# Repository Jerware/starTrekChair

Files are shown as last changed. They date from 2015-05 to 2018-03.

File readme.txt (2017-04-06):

This code adds sound & light to Adam Savage's Star Trek captain's chair
featured in the following Tested video:

https://youtu.be/jaVi06DaTk0

It compiles on Teensy 3.1, requires a Teensy Audio Board, and the two
code bases are designed to work in parallel. Both are available in this
GITHUB repository:

https://github.com/Jerware/

Jeremy Williams wrote the code and designed the sound/LED hardware.

Update April 2017:
This is the second revision of the code & hardware. The sound board now acts
as a master and the LED board is a slave. All buttons are routed solely
to the sound board, and it sends signals to the LED board via hardware
serial. There is also a pin expander IC incorporated instead of the pins
on the underside of the Teensy 3.1.

A PCB is now available from OSH Park:
https://oshpark.com/shared_projects/ZAHpgs72

As always, thanks to the amazing library developers for keeping Arduino coding
from becoming a chore. You are all giants. I'll monitor the feedback on Github
from time to time but this code should be considered unsupported. #LLAP.

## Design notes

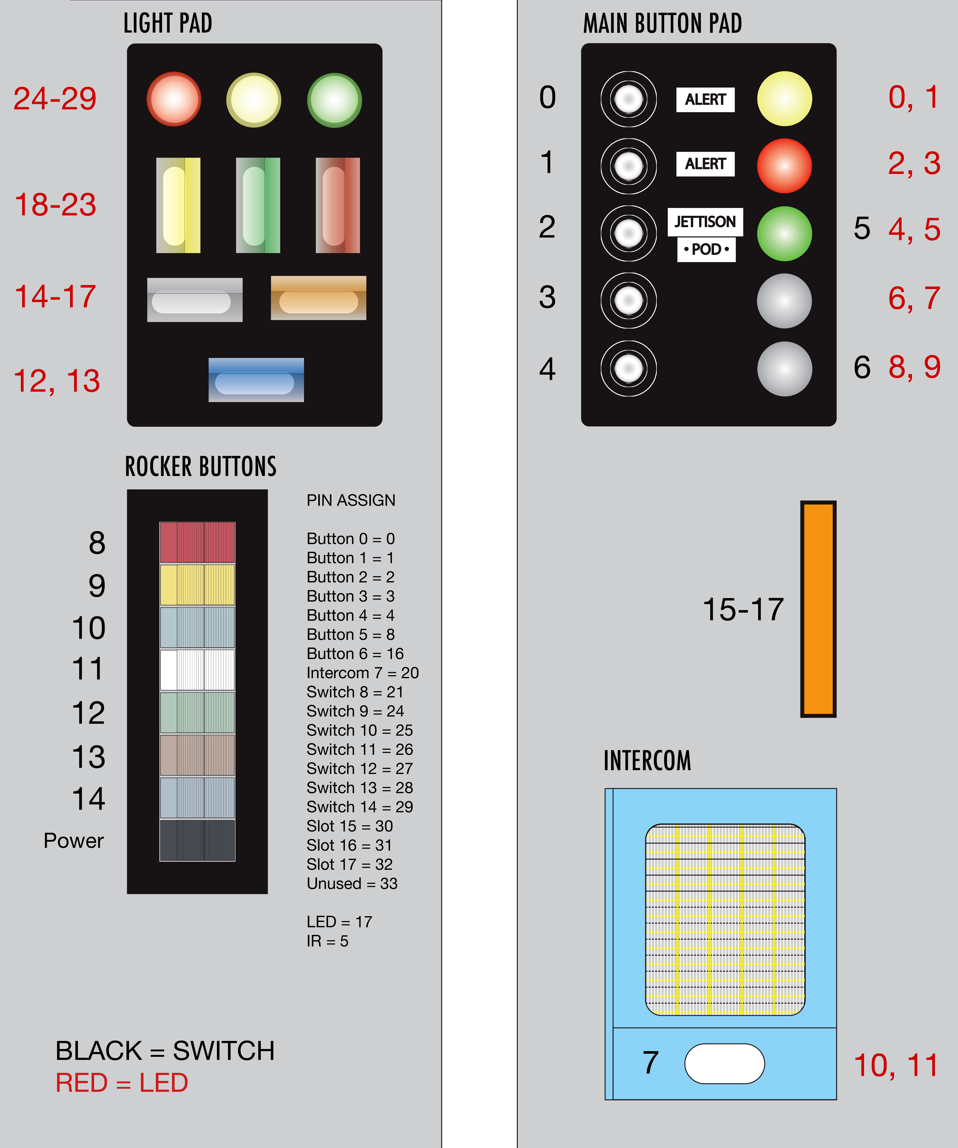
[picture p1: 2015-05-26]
tosChair.png

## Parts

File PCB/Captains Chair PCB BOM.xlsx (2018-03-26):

PART | QUANTITY | TYPE | VALUE | LINK
R1 | 1 | Resistor | 220 Ohm | https://www.digikey.com/product-detail/en/stackpole-electronics-inc/CF14JT220R/CF14JT220RCT-ND/1830334
R2 | 1 | Resistor | 10 kOhm | https://www.digikey.com/product-detail/en/stackpole-electronics-inc/CF14JT10K0/CF14JT10K0CT-ND/1830374
R3 | 1 | Resistor | 2.2 kOhm | https://www.digikey.com/product-detail/en/stackpole-electronics-inc/CF14JT2K20/CF14JT2K20CT-ND/1830358
R4 | 1 | Resistor | 47 Ohm | https://www.digikey.com/product-detail/en/stackpole-electronics-inc/CFM14JT47R0/S47QCT-ND/2617762
R5 | 1 | Resistor | 220 Ohm | https://www.digikey.com/product-detail/en/stackpole-electronics-inc/CF14JT220R/CF14JT220RCT-ND/1830334
D1 | 1 | Diode | 1N4004 | https://www.digikey.com/product-detail/en/micro-commercial-co/1N4004-TP/1N4004-TPMSCT-ND/773691
T1 | 1 | Transistor | 2N3904 | https://www.digikey.com/product-detail/en/on-semiconductor/2N3904BU/2N3904FS-ND/1413
C1 | 1 | Capacitor | 10uf | https://www.digikey.com/product-detail/en/panasonic-electronic-components/ECA-1HM100/P5178-ND/245037
C2 | 1 | Capacitor | .1uf | https://www.digikey.com/product-detail/en/vishay-bc-components/K104K10X7RF5UH5/BC2665CT-ND/2356879
LIGHTS | 1 | Microcontroller | Teensy 3.2 | https://www.pjrc.com/store/teensy32_pins.html
SOUND | 1 | Microcontroller | Teensy 3.2 | https://www.pjrc.com/store/teensy32_pins.html
microSD/AUDIO JACK | 1 | Sound Board | Audio Adaptor Board | https://www.pjrc.com/store/teensy3_audio.html
PWR LED | 1 | LED | 5mm | https://www.adafruit.com/product/679
MCP23017SP | 1 | Port Expander | 16 input/output | https://www.adafruit.com/product/732
SN74HCT245DIL20 | 1 | Level shifter | 20DIP | https://www.digikey.com/product-detail/en/texas-instruments/SN74HCT245N/296-1612-5-ND/277258
7805TV | 1 | Regulator | 3.3V | https://www.digikey.com/product-detail/en/texas-instruments/UCC283T-3/296-11413-5-ND/381558
SWITCHES | 1 | 10x2 | Switch connector | https://www.digikey.com/product-detail/en/sullins-connector-solutions/SBH11-PBPC-D10-ST-BK/S9172-ND/1990065
MISC
Switches Cable | 1 | 10x2 | Female Cable Connector | https://www.amazon.com/Pc-Accessories-Connectors-Yellow-20cm-2PK/dp/B01G7GXHAA/
LEDS, POWER, IR | 3 | Terminal Blocks |  | https://www.digikey.com/product-detail/en/te-connectivity-amp-connectors/282837-2/A113320-ND/2187973
Female Headers for Teensys & Sound | 6 | 14x1 |  | https://www.pjrc.com/store/socket_14x1.html
Male headers for sound board | 2 | 14x1 |  | https://www.pjrc.com/store/header_14x1.html

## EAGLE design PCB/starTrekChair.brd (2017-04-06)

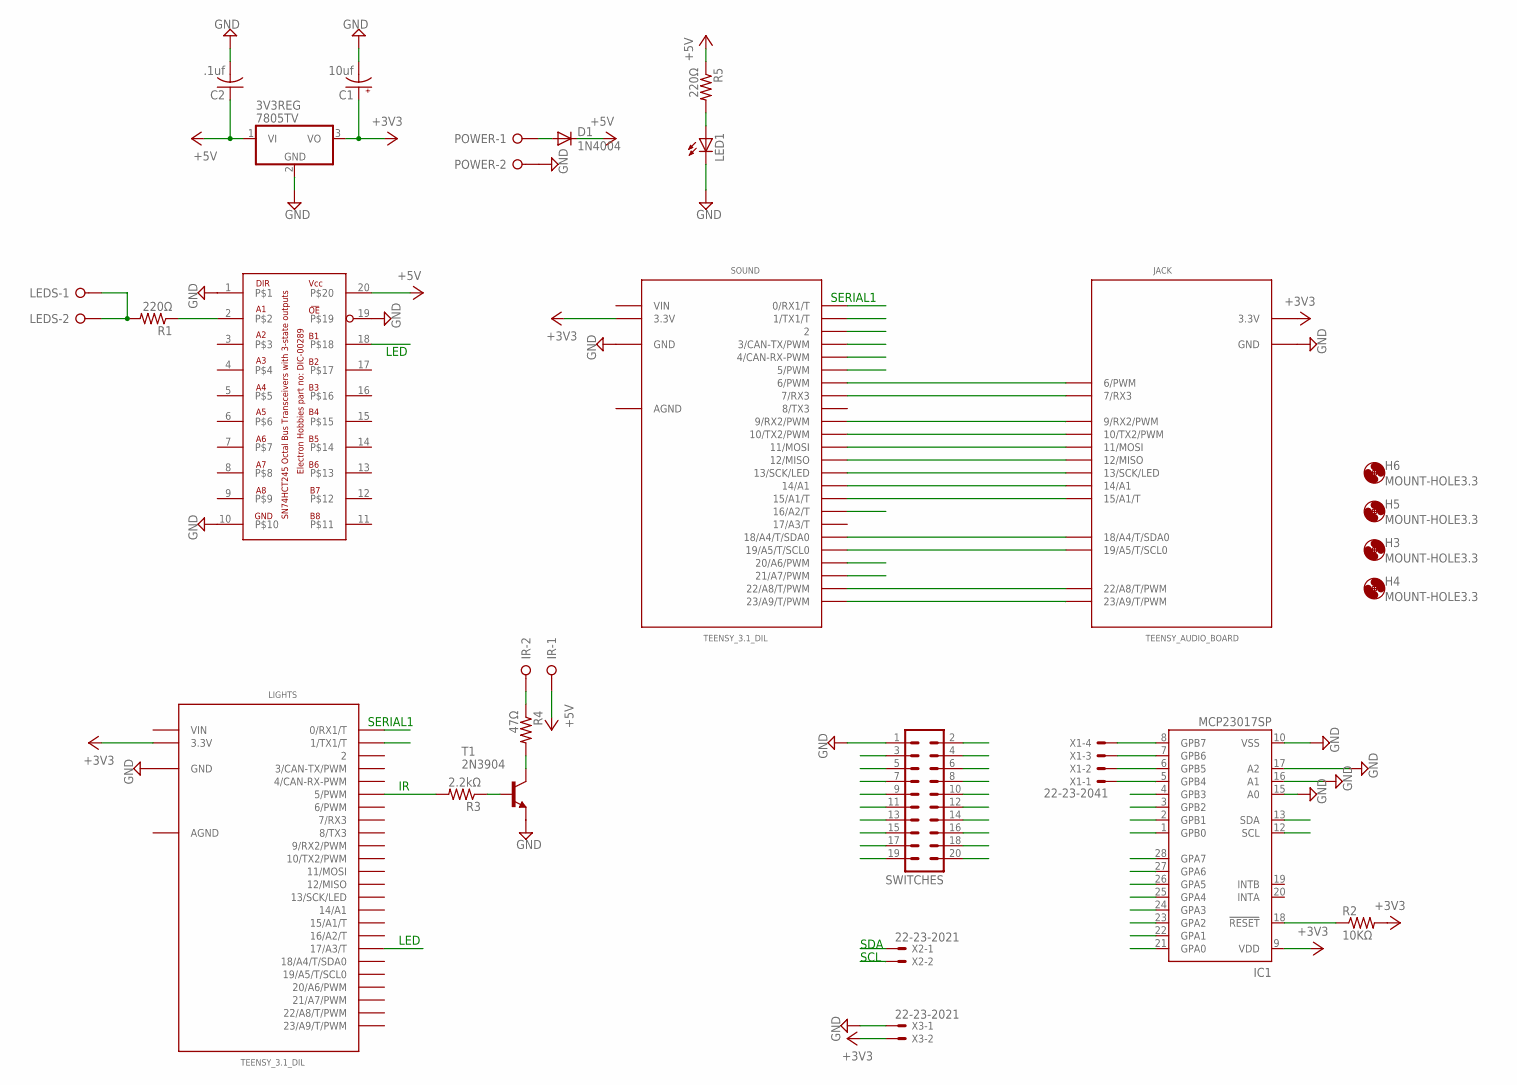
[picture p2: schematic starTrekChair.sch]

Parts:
3V3REG: 7805TV; TO220V
C1: 10uf; E2-4
C2: .1uf; C050-025X075
D1: 1N4004; DO41-10
H3, H4, H5, H6: MOUNT-HOLE3.3; 3,3
IC1: MCP23017SP; DIL28-3
IR: W237-02P; W237-132
JACK: TEENSY_AUDIO_BOARD
LED1: LED5MM
LEDS: W237-02P; W237-132
LIGHTS: TEENSY_3.1_DIL; TEENSY3-DIL
POWER: W237-02P; W237-132
R1, R5: 220Ω; 0207/10
R2: 10KΩ; 0207/10
R3: 2.2kΩ; 0207/10
R4: 47Ω; 0207/10
SOUND: TEENSY_3.1_DIL; TEENSY3-DIL
SWITCHES: ML20
T1: 2N3904; TO92
U$1: SN74HCT245DIL20; DIL20
X1: 22-23-2041
X2, X3: 22-23-2021

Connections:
+3V3: 3V3REG.3 (VO), C1.+, IC1.9 (VDD), JACK.3.3V, LIGHTS.3.3V, R2.2, SOUND.3.3V, X3.2
+5V: 3V3REG.1 (VI), C2.1, D1.C, IR.1, R5.1, U$1.20
AGND: LIGHTS.AGND, SOUND.AGND
GND: 3V3REG.2 (GND), C1.-, C2.2, IC1.10 (VSS), IC1.15 (A0), IC1.16 (A1), IC1.17 (A2), JACK.GND, LED1.K (C), LIGHTS.GND, POWER.2, SOUND.GND, SWITCHES.1, T1.3 (E), U$1.1, U$1.10, U$1.19, X3.1
LED: LIGHTS.17/A3 (17/A3/T), U$1.18
unnamed: JACK.6 (6/PWM), SOUND.6 (6/PWM)
unnamed: JACK.7 (7/RX3), SOUND.7 (7/RX3)
unnamed: JACK.12 (12/MISO), SOUND.12 (12/MISO)
unnamed: JACK.11 (11/MOSI), SOUND.11 (11/MOSI)
unnamed: JACK.10 (10/TX2/PWM), SOUND.10 (10/TX2/PWM)
unnamed: JACK.9 (9/RX2/PWM), SOUND.9 (9/RX2/PWM)
unnamed: JACK.23/A9 (23/A9/T/PWM), SOUND.23/A9 (23/A9/T/PWM)
unnamed: JACK.22/A8 (22/A8/T/PWM), SOUND.22/A8 (22/A8/T/PWM)
unnamed: IC1.18 (!RESET), R2.1
unnamed: LIGHTS.5 (5/PWM), R3.2
unnamed: JACK.15/A1 (15/A1/T), SOUND.15/A1 (15/A1/T)
unnamed: JACK.14/A0 (14/A1), SOUND.14/A0 (14/A1)
unnamed: JACK.13 (13/SCK/LED), SOUND.13 (13/SCK/LED)
unnamed: R1.1, U$1.2
unnamed: LEDS.1, LEDS.2, R1.2
unnamed: IR.2, R4.1
unnamed: R4.2, T1.1 (C)
unnamed: IC1.5 (GPB4), X1.1
unnamed: IC1.6 (GPB5), X1.2
unnamed: IC1.7 (GPB6), X1.3
unnamed: IC1.8 (GPB7), X1.4
unnamed: R3.1, T1.2 (B)
unnamed: LED1.A, R5.2
unnamed: D1.A, POWER.1
RIBBON2: SOUND.2, SWITCHES.2
RIBBON3: SOUND.3 (3/CAN-TX/PWM), SWITCHES.3
RIBBON4: SOUND.4 (4/CAN-RX-PWM), SWITCHES.4
RIBBON5: SOUND.5 (5/PWM), SWITCHES.5
RIBBON6: SOUND.16/A2 (16/A2/T), SWITCHES.6
RIBBON7: SOUND.20/A6 (20/A6/PWM), SWITCHES.7
RIBBON8: SOUND.21/A7 (21/A7/PWM), SWITCHES.8
RIBBON9: IC1.21 (GPA0), SWITCHES.9
RIBBON10: IC1.22 (GPA1), SWITCHES.10
RIBBON11: IC1.23 (GPA2), SWITCHES.11
RIBBON12: IC1.24 (GPA3), SWITCHES.12
RIBBON13: IC1.25 (GPA4), SWITCHES.13
RIBBON14: IC1.26 (GPA5), SWITCHES.14
RIBBON15: IC1.27 (GPA6), SWITCHES.15
RIBBON16: IC1.28 (GPA7), SWITCHES.16
RIBBON17: IC1.1 (GPB0), SWITCHES.17
RIBBON18: IC1.2 (GPB1), SWITCHES.18
RIBBON19: IC1.3 (GPB2), SWITCHES.19
RIBBON20: IC1.4 (GPB3), SWITCHES.20
SCL: IC1.12 (SCL), JACK.19/A5 (19/A5/T/SCL0), SOUND.19/A5 (19/A5/T/SCL0), X2.2
SDA: IC1.13 (SDA), JACK.18/A4 (18/A4/T/SDA0), SOUND.18/A4 (18/A4/T/SDA0), X2.1
S_RX: LIGHTS.1 (1/TX1/T), SOUND.0 (0/RX1/T)
S_TX: LIGHTS.0 (0/RX1/T), SOUND.1 (1/TX1/T)
VIN: LIGHTS.VIN, SOUND.VIN

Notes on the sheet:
LED
SERIAL1
SDA
SCL

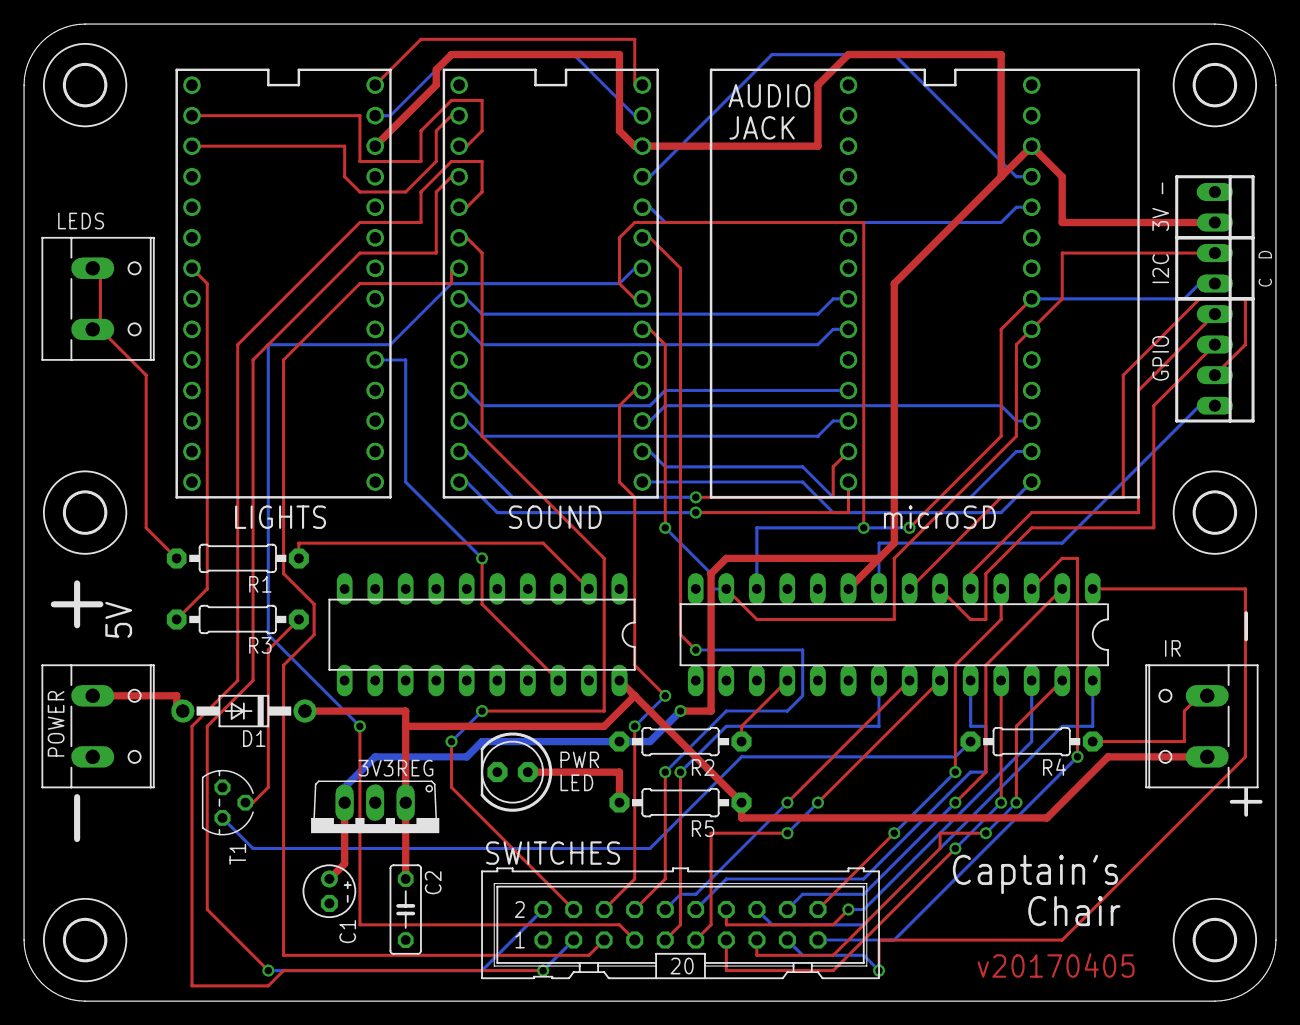
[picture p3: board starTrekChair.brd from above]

Board: 2 copper layers, 104.1 x 81.3 mm, 29 parts (0 on the bottom side), 53 nets.

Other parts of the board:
H1, H2: MOUNT-HOLE3.3; 3,3

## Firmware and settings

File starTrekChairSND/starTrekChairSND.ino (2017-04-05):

// starTrekChairSND release 20160319
//
// This code controls the LEDs on Adam Savage's Star Trek captain's chair
// featured in the following Tested video:
//
// https://youtu.be/jaVi06DaTk0
//
// It compiles on Teensy 3.1 and is designed to work in parallel with the 
// sound code. Both sources are available in this GITHUB repository:
//
// https://github.com/Jerware/
//
// Jeremy Williams wrote the code and designed the sound/LED hardware.
// This is the second revision of the code & hardware. The sound board now
// acts as a master and the LED board is a slave. All buttons are routed
// solely to the sound board, and it sends signals to the LED board
// via hardware serial. There is also a pin expander IC incorporated 
// instead of the pins on the underside of the Teensy 3.1.
//
// As always, thanks to the amazing library developers for keeping Arduino coding
// from becoming a chore. You are all giants. I'll monitor the feedback on Github
// from time to time but this code should be considered unsupported. #LLAP.

#include <Audio.h>
#include <Wire.h>
#include <SPI.h>
#include <SD.h>
#include <Bounce2.h>
#include <Bounce2mcp.h>
#include <Entropy.h>
#include <FastLED.h>
#include "Adafruit_MCP23017.h"

#define HWSERIAL Serial1

Adafruit_MCP23017 mcp;

byte lastButton;
boolean switchClosed;
int slotMode;
boolean moviePlaying;

// GUItool: begin automatically generated code
AudioPlaySdWav           soundButtons;       //xy=223,156
AudioPlaySdWav           soundRocker;       //xy=225,228
AudioPlaySdWav           soundBackground;       //xy=225,395
AudioPlaySdWav           soundIntercom;       //xy=230,489
AudioMixer4              mixer3;         //xy=528,500
AudioMixer4              mixer1;         //xy=529,307
AudioMixer4              mixer2;         //xy=724,398
AudioFilterBiquad        intercomFilter;        //xy=714,554
AudioOutputI2S           i2s1;           //xy=892,494
AudioConnection          patchCord1(soundButtons, 0, mixer1, 0);
AudioConnection          patchCord2(soundButtons, 1, mixer1, 1);
AudioConnection          patchCord3(soundRocker, 0, mixer1, 2);
AudioConnection          patchCord4(soundRocker, 1, mixer1, 3);
AudioConnection          patchCord5(soundBackground, 0, mixer2, 1);
AudioConnection          patchCord6(soundBackground, 1, mixer2, 2);
AudioConnection          patchCord7(soundIntercom, 0, mixer3, 0);
AudioConnection          patchCord8(soundIntercom, 1, mixer3, 1);
AudioConnection          patchCord9(mixer3, intercomFilter);
AudioConnection          patchCord10(mixer1, 0, mixer2, 0);
AudioConnection          patchCord11(intercomFilter, 0, i2s1, 1);
AudioConnection          patchCord12(mixer2, 0, i2s1, 0);
// GUItool: end automatically generated code

// Create an object to control the audio shield.
AudioControlSGTL5000 audioShield;

// Bounce Teensy Pins
Bounce button1 = Bounce();
Bounce button2 = Bounce();
Bounce button3 = Bounce();
Bounce button4 = Bounce();
Bounce button5 = Bounce();
Bounce button6 = Bounce();
Bounce button7 = Bounce();

// Debounce MCP23017 Pins
BounceMcp buttonIntercom = BounceMcp();
BounceMcp rocker1 = BounceMcp();
BounceMcp rocker2 = BounceMcp();
BounceMcp rocker3 = BounceMcp();
BounceMcp rocker4 = BounceMcp();
BounceMcp rocker5 = BounceMcp();
BounceMcp rocker6 = BounceMcp();
BounceMcp rocker7 = BounceMcp();
BounceMcp slot1 = BounceMcp();
BounceMcp slot2 = BounceMcp();
BounceMcp slot3 = BounceMcp();
BounceMcp other1 = BounceMcp();


void setup() {
  Serial.begin(57600);
  HWSERIAL.begin(38400);
  delay(1000);
  Serial.println("Hello there!");

  // Start I²C bus as master
  Wire.begin();

  mcp.begin();      // use default address 0

  Entropy.Initialize();

  // Configure the pushbutton pins for pullups.
  // Each button should connect from the pin to GND.
  // Teensy Pins
  pinMode(2, INPUT_PULLUP);
  pinMode(3, INPUT_PULLUP);
  pinMode(4, INPUT_PULLUP);
  pinMode(5, INPUT_PULLUP);
  pinMode(16, INPUT_PULLUP);
  pinMode(20, INPUT_PULLUP);
  pinMode(21, INPUT_PULLUP);
  button1.attach(2);
  button2.attach(3);
  button3.attach(4);
  button4.attach(5);
  button5.attach(16);
  button6.attach(20);
  button7.attach(21);
  button1.interval(35);
  button2.interval(35);
  button3.interval(35);
  button4.interval(35);
  button5.interval(35);
  button6.interval(35);
  button7.interval(35);

  // MCP23017 Pins
  for (int p=0; p<16; p++)
  {
    mcp.pinMode(p, INPUT);
    mcp.pullUp(p, HIGH);  // turn on a 100K pullup internally
  }
  buttonIntercom.attach(mcp, 0, 35);
  rocker1.attach(mcp, 1, 35);
  rocker2.attach(mcp, 2, 35);
  rocker3.attach(mcp, 3, 35);
  rocker4.attach(mcp, 4, 35);
  rocker5.attach(mcp, 5, 35);
  rocker6.attach(mcp, 6, 35);
  rocker7.attach(mcp, 7, 35);
  slot1.attach(mcp, 8, 35);
  slot2.attach(mcp, 9, 35);
  slot3.attach(mcp, 10, 35);

  // Audio connections require memory to work.  For more
  // detailed information, see the MemoryAndCpuUsage example
  AudioMemory(64);

  // turn on the output
  audioShield.enable();
  audioShield.volume(.8);
  delay(1000);
  intercomFilter.setHighpass(0, 800, 0.707);

  // by default the Teensy 3.1 DAC uses 3.3Vp-p output
  // if your 3.3V power has noise, switching to the
  // internal 1.2V reference can give you a clean signal
  //dac.analogReference(INTERNAL);

  // reduce the gain on mixer channels, so more than 1
  // sound can play simultaneously without clipping
  float gainLevel = .4;
  mixer2.gain(0, gainLevel);
  mixer2.gain(1, gainLevel);
  mixer2.gain(2, gainLevel);
  mixer2.gain(3, gainLevel);
  mixer3.gain(0, gainLevel);
  mixer3.gain(1, gainLevel);
  mixer3.gain(2, gainLevel);
  mixer3.gain(3, gainLevel);

  SPI.setMOSI(7);
  SPI.setSCK(14);
  if (!(SD.begin(10))) {
    // stop here, but print a message repetitively
    while (1) {
      Serial.println("Unable to access the SD card");
      delay(500);
    }
  }

  // Store the button states
  button1.update();
  button2.update();
  button3.update();
  button4.update();
  button5.update();
  button6.update();
  button7.update();
  buttonIntercom.update();
  rocker1.update();
  rocker2.update();
  rocker3.update();
  rocker4.update();
  rocker5.update();
  rocker6.update();
  rocker7.update();
  slot1.update();
  slot2.update();
  slot3.update();
  other1.update();
}

void loop() {
  // Update all the button objects
  button1.update();
  button2.update();
  button3.update();
  button4.update();
  button5.update();
  button6.update();
  button7.update();
  buttonIntercom.update();
  rocker1.update();
  rocker2.update();
  rocker3.update();
  rocker4.update();
  rocker5.update();
  rocker6.update();
  rocker7.update();
  slot1.update();
  slot2.update();
  slot3.update();
  other1.update();

  // When the buttons are pressed, just start a sound playing.
  // The audio library will play each sound through the mixers
  // so combinations of banks can play simultaneously.

  // main buttons
  if (button1.fell()) {
    Serial.println("PRESSED: Button 1");
    if (lastButton == 1 && soundButtons.isPlaying()) {
      soundButtons.stop();
      lastButton = 0;
      lightShow(0);
    }
    else
    {
      lastButton = 1;
      soundButtons.play("01.wav");
      Serial.println("Playing 01.wav");
      lightShow(1);
    }
  }

  if (button2.fell()) {
    Serial.println("PRESSED: Button 2");
    if (lastButton == 2 && soundButtons.isPlaying()) {
      soundButtons.stop();
      lastButton = 0;
      lightShow(0);
    }
    else
    {
      lastButton = 2;
      soundButtons.play("02.wav");
      Serial.println("Playing 02.wav");
      lightShow(2);
    }
  }

  if (button3.fell()) {
    Serial.println("PRESSED: Button 3");
    if (lastButton == 3 && soundButtons.isPlaying()) {
      soundButtons.stop();
      lastButton = 0;
      lightShow(0);
    }
    else
    {
      lastButton = 3;
      soundButtons.play("03.wav");
      Serial.println("Playing 03.wav");
      lightShow(3);
    }
  }

  if (button4.fell()) {
    Serial.println("PRESSED: Button 4");
    if (lastButton == 4 && soundButtons.isPlaying()) {
      soundButtons.stop();
      lastButton = 0;
      lightShow(0);
    }
    else
    {
      if (!moviePlaying)
      {
        lastButton = 4;
        soundButtons.play("04.wav");
        Serial.println("Playing 04.wav");
        lightShow(4);
      }
    }
  }

  if (button5.fell()) {
    Serial.println("PRESSED: Button 5");
    if (!moviePlaying)
    {
      lastButton = 5;
      byte random_byte = random8(1,8); // returns a value from 1 to 7
      char fileNumber[2];
      char fileName[13];
      strcpy_P(fileName, PSTR("05_0"));
      itoa(random_byte, fileNumber, 10);
      strcat(fileName, fileNumber);
      strcat(fileName, ".wav");
      soundButtons.play(fileName);
      Serial.print("Playing ");
      Serial.println(fileName);
      lightShow(5);
    }
  }

  if (button6.fell()) {
    Serial.println("PRESSED: Button 6");
    lightShow(6);
    if (lastButton == 6 && soundBackground.isPlaying()) {
      soundBackground.stop();
      lastButton = 0;
    }
    else
    {
      if (!moviePlaying)
      {
        lastButton = 6;
        soundBackground.play("06.wav");
        Serial.println("Playing 06.wav");
      }
    }
  }
  
  else if (button6.rose())
  {
    lightShow(0);
  }

  if (button7.fell()) {
    Serial.println("PRESSED: Button 7");
    lightShow(7);
    if (lastButton == 7 && soundBackground.isPlaying()) {
      soundBackground.stop();
      lastButton = 0;
    }
    else
    {
      if (!moviePlaying)
      {
        lastButton = 7;
        soundBackground.play("07.wav");
        Serial.println("Playing 07.wav");
      }
    }
  }
  
  else if (button7.rose())
  {
    lightShow(0);
  }

  // intercom
  if (buttonIntercom.fell()) {
    Serial.println("PRESSED: Intercom");
    soundIntercom.play("08_01.wav");
    Serial.println("Playing 08_01.wav");
    lightShow(8);
  }
  if (buttonIntercom.rose()) {
    lightShow(0);
    byte random_byte = Entropy.random(1,20); // returns a value from 1 to 19
    char fileNumber[3];
    char fileName[13];
    if (random_byte < 10) strcpy_P(fileName, PSTR("08_up_0"));
    else strcpy_P(fileName, PSTR("08_up_"));
    itoa(random_byte, fileNumber, 10);
    strcat(fileName, fileNumber);
    strcat(fileName, ".wav");
    soundIntercom.play(fileName);
    Serial.print("Playing ");
    Serial.println(fileName);
  }

  // rocker switches
  if (rocker1.fell()) {
    Serial.println("PRESSED: Rocker 1");
    lightShow(111);
    soundRocker.play("09_01.wav");
    Serial.println("Playing 09_01.wav");
  }
  if (rocker1.rose()) {
    lightShow(110);
    soundRocker.play("09_02.wav");
    Serial.println("Playing 09_02.wav");
  }
  if (rocker2.fell()) {
    Serial.println("PRESSED: Rocker 2");
    lightShow(121);
    soundRocker.play("10_01.wav");
    Serial.println("Playing 10_01.wav");
  }
  if (rocker2.rose()) {
    lightShow(120);
    soundRocker.play("10_02.wav");
    Serial.println("Playing 10_02.wav");
  }
  if (rocker3.fell()) {
    Serial.println("PRESSED: Rocker 3");
    lightShow(131);
    soundRocker.play("11_01.wav");
    Serial.println("Playing 11_01.wav");
  }
  if (rocker3.rose()) {
    lightShow(130);
    soundRocker.play("11_02.wav");
    Serial.println("Playing 11_02.wav");
  }
  if (rocker4.fell()) {
    Serial.println("PRESSED: Rocker 4");
    lightShow(141);
    soundRocker.play("12_01.wav");
    Serial.println("Playing 12_01.wav");
  }
  if (rocker4.rose()) {
    lightShow(140);
    soundRocker.play("12_02.wav");
    Serial.println("Playing 12_02.wav");
  }
  if (rocker5.fell()) {
    Serial.println("PRESSED: Rocker 5");
    lightShow(151);
    soundRocker.play("13_01.wav");
    Serial.println("Playing 13_01.wav");
  }
  if (rocker5.rose()) {
    lightShow(150);
    soundRocker.play("13_02.wav");
    Serial.println("Playing 13_02.wav");
  }
  if (rocker6.fell()) {
    Serial.println("PRESSED: Rocker 6");
    lightShow(161);
    soundRocker.play("14_01.wav");
    Serial.println("Playing 14_01.wav");
  }
  if (rocker6.rose()) {
    lightShow(160);
    soundRocker.play("14_02.wav");
    Serial.println("Playing 14_02.wav");
  }
  if (rocker7.fell()) {
    Serial.println("PRESSED: Rocker 7");
    lightShow(171);
    soundBackground.play("15.wav");
    Serial.println("Playing 15.wav");
  }
  if (rocker7.rose()) {
    lightShow(170);
    soundBackground.stop();
    Serial.println("Stopping soundBackground");
  }

  // card slot

  if (slot1.fell()) Serial.println("PRESSED: Slot 1");
  if (slot2.fell()) Serial.println("PRESSED: Slot 2");
  if (slot3.fell()) Serial.println("PRESSED: Slot 3");


  if (slot1.fell() || slot2.fell() || slot3.fell()) 
  {
    Serial.println("Card inserted...");
    soundButtons.stop();
    soundBackground.stop();
    delay(250);
    slot1.update();
    slot2.update();
    slot3.update();
    if (!slot1.read() && slot2.read() && slot3.read())
    {
      soundButtons.play("key1.wav");
      delay(1000);
      if (!allRockersOn()) soundBackground.play("song1.wav");
      else
      {
        moviePlaying = true;
        soundBackground.stop();
      }
      Serial.println("Slot mode 100");
      slotMode = 100;
    }
    else if (slot1.read() && !slot2.read() && slot3.read())
    {
      soundButtons.play("key2.wav");
      delay(1000);
      if (!allRockersOn()) soundBackground.play("song2.wav");
      else
      {
        moviePlaying = true;
        soundBackground.stop();
      }
      Serial.println("Slot mode 010");
      slotMode = 10;
    }
    else if (slot1.read() && slot2.read() && !slot3.read())
    {
      soundButtons.play("key3.wav");
      delay(1000);
      if (!allRockersOn()) soundBackground.play("song3.wav");
      else
      {
        moviePlaying = true;
        soundBackground.stop();
      }
      Serial.println("Slot mode 001");
      slotMode = 1;
    }
    else if (!slot1.read() && !slot2.read() && slot3.read())
    {
      soundButtons.play("key4.wav");
      delay(1000);
      if (!allRockersOn()) soundBackground.play("song4.wav");
      else
      {
        moviePlaying = true;
        soundBackground.stop();
      }
      Serial.println("Slot mode 110");
      slotMode = 110;
    }
    else if (!slot1.read() && slot2.read() && !slot3.read())
    {
      soundButtons.play("key5.wav");
      delay(1000);
      if (!allRockersOn()) soundBackground.play("song5.wav");
      else moviePlaying = true;
      Serial.println("Slot mode 101");
      slotMode = 101;
    }
    else if (slot1.read() && !slot2.read() && !slot3.read())
    {
      soundButtons.play("key6.wav");
      delay(1000);
      if (!allRockersOn()) soundBackground.play("song6.wav");
      else
      {
        moviePlaying = true;
        soundBackground.stop();
      }
      Serial.println("Slot mode 011");
      slotMode = 11;
    }
    else if (!slot1.read() && !slot2.read() && !slot3.read())
    {
      soundButtons.play("key7.wav");
      delay(1000);
      if (!allRockersOn()) soundBackground.play("song7.wav");
      else
      {
        moviePlaying = true;
        soundBackground.stop();
      }
      Serial.println("Slot mode 111");
      slotMode = 111;
    }
  }

  // card removed
  else if (slot1.rose() || slot2.rose() || slot3.rose()) 
  {
    Serial.println("Card removed...");
    if (moviePlaying) moviePlaying = false;
    soundBackground.stop();
    soundButtons.play("key0.wav");
    slotMode = 0;
    delay(250);
    slot1.update();
    slot2.update();
    slot3.update();
  }


  // volume control
  //  float vol = analogRead(15);
  //  vol = vol / 1024;
  //  audioShield.volume(vol);
}

boolean allRockersOn()
{
  if (!rocker1.read() && !rocker2.read() && !rocker3.read() && !rocker4.read() && !rocker5.read() && !rocker6.read() && !rocker7.read())
  {
    return true;
  }
  else return false;
}

void lightShow(int seq)
{
  Serial.print("Sending: ");
  Serial.println(seq);
  HWSERIAL.println(seq, DEC);
}


// Additionl notes on FastLED compact palettes:
//
// Normally, in computer graphics, the palette (or "color lookup table")
// has 256 entries, each containing a specific 24-bit RGB color.  You can then
// index into the color palette using a simple 8-bit (one byte) value.
// A 256-entry color palette takes up 768 bytes of RAM, which on Arduino
// is quite possibly "too many" bytes. 
//
// FastLED does offer traditional 256-element palettes, for setups that
// can afford the 768-byte cost in RAM.
//
// However, FastLED also offers a compact alternative.  FastLED offers
// palettes that store 16 distinct entries, but can be accessed AS IF
// they actually have 256 entries; this is accomplished by interpolating
// between the 16 explicit entries to create fifteen intermediate palette 
// entries between each pair.
//
// So for example, if you set the first two explicit entries of a compact 
// palette to Green (0,255,0) and Blue (0,0,255), and then retrieved 
// the first sixteen entries from the virtual palette (of 256), you'd get
// Green, followed by a smooth gradient from green-to-blue, and then Blue.

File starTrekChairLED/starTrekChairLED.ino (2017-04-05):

// starTrekChairLED release 20160319
//
// This code controls the LEDs on Adam Savage's Star Trek captain's chair
// featured in the following Tested video:
//
// https://youtu.be/jaVi06DaTk0
//
// It compiles on Teensy 3.1 and is designed to work in parallel with the 
// sound code. Both sources are available in this GITHUB repository:
//
// https://github.com/Jerware/
//
// Jeremy Williams wrote the code and designed the sound/LED hardware.
// This is the second revision of the code & hardware. The sound board now
// acts as a master and the LED board is a slave. All buttons are routed
// solely to the sound board, and it sends signals to the LED board
// via hardware serial. There is also a pin expander IC incorporated 
// instead of the pins on the underside of the Teensy 3.1.
//
// As always, thanks to the amazing library developers for keeping Arduino coding
// from becoming a chore. You are all giants. I'll monitor the feedback on Github
// from time to time but this code should be considered unsupported. #LLAP.

#include "FastLED.h"
#include <IRremote.h>

#define HWSERIAL Serial1

IRsend irsend;

byte lastButton;
boolean switchClosed;
int slotMode;
boolean moviePlaying;
byte lightShow; // received i2c command

// LED SETUP
#define LED_PIN     17
#define NUM_LEDS    318
#define BRIGHTNESS  255
#define LED_TYPE    NEOPIXEL
#define COLOR_ORDER GRB
int UPDATES_PER_SECOND = 100;
long showRate = 100;
CRGB leds[NUM_LEDS];
CRGBPalette16 currentPalette;
TBlendType    currentBlending;
extern CRGBPalette16 myRedWhiteBluePalette;
extern const TProgmemPalette16 myRedWhiteBluePalette_p PROGMEM;
extern const TProgmemPalette16 alarm1_p PROGMEM;
extern const TProgmemPalette16 alarm2_p PROGMEM;
long ledUpdate;
long effectDuration;
long effectStopTime;
byte ledColor;
int ledPhase;
long lightPanelTick;
long lightPanelTickDuration = 500; // time between ticks in ms
byte lightPanelLife = 10; // 0-255 likelihood of panel blinks

void setup() {
  Serial.begin(57600);
  HWSERIAL.begin(38400);
  delay(1000);
  Serial.println("Hello there!");
  
  FastLED.addLeds<LED_TYPE, LED_PIN>(leds, NUM_LEDS);
  FastLED.setBrightness(  BRIGHTNESS );
  currentPalette = RainbowColors_p;
  currentBlending = LINEARBLEND;
  
  resetJewels();
  leds[10] = CRGB::White;
  leds[11] = CRGB::White;
  Serial.println("All systems online, Captain!");
}

void checkHWSerial()
{
  int incomingByte;
  if (HWSERIAL.available() > 0) {
    incomingByte = HWSERIAL.parseInt();
    Serial.print("Message from Starfleet: ");
    Serial.println(incomingByte);
    lightShow = incomingByte;
    HWSERIAL.clear();
  }
}

void loop() {
  checkHWSerial();
  if (lightShow == 0)
  {
    lightShow = 255;
    resetJewels();
  }
  // main buttons
  else if (lightShow == 1) {
    Serial.println("Lightshow 1");
    lightShow = 255;
    ledColor = 0;
    buttonPressed(1, 57000, 90);  // button, duration in ms, updates per second
  }
  else if (lightShow == 2) {
    Serial.println("Lightshow 2");
    lightShow = 255;
    ledColor = 0;
    buttonPressed(2, 33000, 90);
  }
  else if (lightShow == 3) {
    Serial.println("Lightshow 3");
    lightShow = 255;
    ledColor = 0;
    buttonPressed(3, 64000, 15);
  }
  else if (lightShow == 4) {
    Serial.println("Lightshow 4");
    lightShow = 255;
    if (moviePlaying)
    {
      irsend.sendSony(0xA70, 12); // OK/Pause
    }
    ledColor = 0;
    buttonPressed(4, 11000, 12);
  }
  else if (lightShow == 5) {
    Serial.println("Lightshow 5");
    lightShow = 255;
    if (moviePlaying)
    {
      irsend.sendSony(0x338, 12); // left
    }
    lastButton = 0;
    ledColor = 255;
    buttonPressed(5, 10000, 100);
  }
  else if (lightShow == 6) {
    Serial.println("Lightshow 5");
    lightShow = 255;
    if (moviePlaying)
    {
      irsend.sendSony(0x1D0, 12); // TV-RETURN/Kill omxplayer
    }
    leds[8] = CRGB::Red;
    leds[9] = CRGB::Red;
  }
//  if (button6.risingEdge()) {
//    leds[8] = CRGB::White;
//    leds[9] = CRGB::White;
//  }
  else if (lightShow == 7) {
    lightShow = 255;
    if (moviePlaying)
    {
      irsend.sendSony(0x738, 12); // right
    }
    leds[4] = CRGB::Black;
    leds[5] = CRGB::Black;
  }
//  if (button7.risingEdge()) {
//    leds[4] = CRGB::White;
//    leds[5] = CRGB::White;
//  }
  
  // intercom
  else if (lightShow == 8) {
    lightShow = 255;
    leds[10] = CRGB::Yellow;
    leds[11] = CRGB::Yellow;
  }
//  if (buttonIntercom.risingEdge()) {
//    leds[10] = CRGB::White;
//    leds[11] = CRGB::White;
//  }
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

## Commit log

2015-05-26 Initial Commit
    Switch & pin assignments
2017-04-05 Added master/slave board relationship
    This is the second revision of the code & hardware. The sound board now acts as a master and the LED board is a slave. All buttons are routed solely to the sound board, and it sends signals to the LE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
2017-04-05 Updated description w/PCB link
2017-04-05 Added PCB Source Files
    [starTrekChair.brd, starTrekChair.sch]
2017-04-06 Tweaked silkscreen
    [starTrekChair.brd]
2018-03-26 Added BOM
    [Captains Chair PCB BOM.xlsx]
